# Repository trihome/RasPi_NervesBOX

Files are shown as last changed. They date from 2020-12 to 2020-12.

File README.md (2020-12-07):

# Nerves BOX for Raspberry Pi

## はじめに

このボードは、産業用に使用される機器（例：24V駆動のスイッチ、センサー、リレーなど）をRaspberry Piへ接続できるようにします。

詳しくは、Qiitaの記事「[Elixir/NervesでPLC(多機能リレー)を作ってみた](https://qiita.com/myasu/private/a6664d3a3c76503affc7)」をご覧ください。

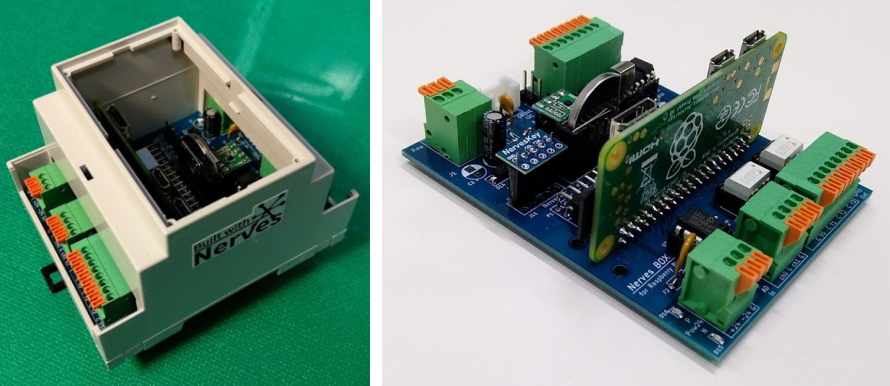
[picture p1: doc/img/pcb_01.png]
pcb01 外観

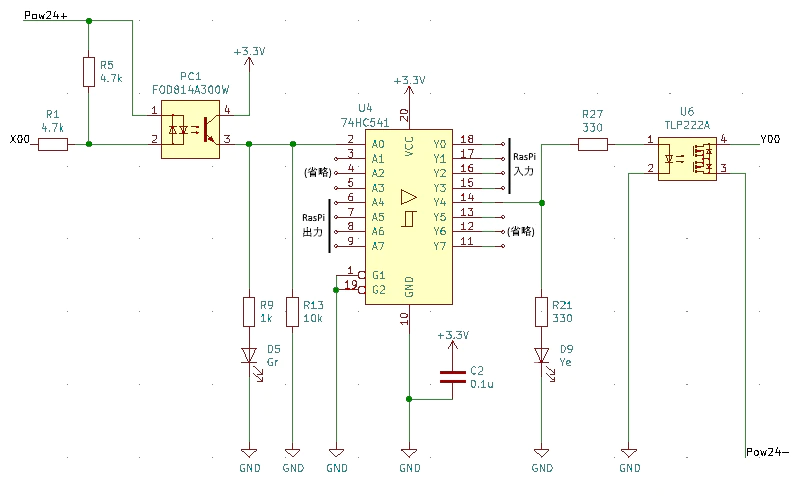
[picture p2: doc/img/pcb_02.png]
pcb02 基板


## 仕様

|機能|仕様|補足|
|:--|:--|:--|
|出力|4ch（フォトリレー絶縁）|シンク（NPN）・ソース（PNP）駆動切り替え可能。各chの動作確認LEDあり。|
|入力|4ch（フォトカプラ絶縁）|〃|
|AD変換|10bit 2ch|非絶縁・入力保護のダイオード付き|
|時刻保持|リアルタイムクロックDS1307|ボタン電池でバックアップ|
|GROVEコネクタ|あり、I2C x 1|5V電源タイプ|
|外部UART端子|あり x 1|RaspberryPiのUARTに直結|
|電源|5V系/24V系は個別に供給|それぞれポリスイッチ（過電流防止）あり|

**J5, J7の接続**

|対応表|GPIO（BCM表記）|本機の端子|
|:--|:--|:--|
|入力|12|X0|
|〃|16|X1|
|〃|20|X2|
|〃|21|X3|
|出力|6|Y0|
|〃|13|Y1|
|〃|19|Y2|
|〃|26|Y3|

**J2の接続**

|駆動したい方法|Pow24+In|Pow24-In||D16|D13||X側COM端子|Y側COM端子|
|:--|:--|:--|:--|:--|:--|:--|:--|:--|
|シンク|+24V|GND|→|点灯|消灯||GND|+24V|
|ソース|GND|+24V|→|消灯|点灯||+24V|GND|

## 作り方

[Manual](doc/README_pcb.jp.md)をご覧ください。

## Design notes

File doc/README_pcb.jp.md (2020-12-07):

# Nerves BOX for Raspberry Pi

## 1.作り方

### (1)PCB

`gerber`ディレクトリの中のファイル一式を、PCB業者に制作依頼します。

（一例）

- [Fusion PCB](https://www.fusionpcb.jp/)
- [P板.com](https://www.p-ban.com/)

#### Fusion PCBでの注文手順

[手順参考](https://github.com/trihome/RasPi_PiFA/blob/master/doc/README_pcb.jp.md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)

※2020年3月時点の手順です。
※費用はPayPalアカウントかクレジットカードで支払います。

### (2)部品表

大半の部品は、秋月電子通商さんで購入できます。
一部、取り扱いのない部品については、マルツオンラインさん、共立電子産業さん、千石電商さんなどから購入可能です。

[部品表](../NBoxRpi.csv)

#### 補足

NPN（シンク）駆動だけで使用する場合は、より入手性の良い（かつ安価な）下記の部品でも対応可能です。
（J2の接続は必ず”シンク”の繋ぎ方にしてください）

|部品番号|変更前|変更後|入手先|
|:--|:--|:--|:--|
|PC1 PC2 PC3 PC4 |FOD814A300W|TLP627|https://akizukidenshi.com/catalog/g/gI-07691/|
|U6 U7 U8 U9 |TLP222A|〃|〃|

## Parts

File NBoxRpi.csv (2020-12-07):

Reference | Quantity | Value | URL
BT1 | 1 | CH243-2032LF | https://akizukidenshi.com/catalog/g/gP-02019/
C3 | 1 | 100uF | https://akizukidenshi.com/catalog/g/gP-03122/
C1 C2 C4 | 3 | 0.1uF | https://akizukidenshi.com/catalog/g/gP-10147/
C5 | 1 | 470uF | https://akizukidenshi.com/catalog/g/gP-10272/
D1 D2 D3 D4 | 4 | 1N4148W | https://akizukidenshi.com/catalog/g/gI-07084/
D10 D16 D13 | 2 | LED Red | https://akizukidenshi.com/catalog/g/gI-03978/
D15 | 1 | SBR1A40SA | https://akizukidenshi.com/catalog/g/gI-07418/
D5 D6 D7 D8 | 4 | LED Greeen | https://akizukidenshi.com/catalog/g/gI-03980/
D9 D11 D12 D14 | 4 | LED Yellow | https://akizukidenshi.com/catalog/g/gI-03984/
F1 | 1 | 0.17A(MAX0.34) | https://akizukidenshi.com/catalog/g/gP-12627/
F2 | 1 | 0.5A(MAX1A) | https://akizukidenshi.com/catalog/g/gP-12628/
J1 | 1 | GROVE CONN | https://www.marutsu.co.jp/pc/i/829425/
J3 J9 | 1 | Pin Header 3 | https://akizukidenshi.com/catalog/g/gC-00167/
J8 | 1 | Pin Header 4 | https://akizukidenshi.com/catalog/g/gC-00167/
J4 | 1 | TB401-1-3-E | https://akizukidenshi.com/catalog/g/gP-01405/
J5 J7 | 1 | TB401-1-8-E | https://akizukidenshi.com/catalog/g/gP-07757/
J6 J2 | 1 | TB401-1-4-E | https://akizukidenshi.com/catalog/g/gP-07756/
P1 | 1 | RasPi CONN | https://www.marutsu.co.jp/pc/i/59246/
R1 R2 R3 R4 R5 R6 R7 R8 R26 R31 | 10 | 4.7k | https://eleshop.jp/shop/g/gABO36V/
R13 R14 R15 R16 R17 R18 R19 R20 R32 R33 R34 R35 R40 R41 | 14 | 10k | https://eleshop.jp/shop/g/gABQ364/
R21 R23 R24 R25 R27 R28 R29 R30 | 8 | 330 | https://eleshop.jp/shop/g/gABO363/
R22 | 1 | 470 | https://eleshop.jp/shop/g/gABO367/
R9 R10 R11 R12 R36 R37 R38 R39 | 8 | 1k | https://eleshop.jp/shop/g/gABO36F/
(ICソケット8Pin) | 4 |  | https://akizukidenshi.com/catalog/g/gP-00017/
U1 | 1 | AE-PCA9306 | https://akizukidenshi.com/catalog/g/gM-05452/
U2 | 1 | MCP3002 | https://akizukidenshi.com/catalog/g/gI-02584/
PC1 PC2 PC3 PC4 | 4 | FOD814A300W | https://akizukidenshi.com/catalog/g/gI-06483/
U6 U7 U8 U9 | 4 | TLP222A | https://akizukidenshi.com/catalog/g/gI-07672/
U3 | 1 | DS1307+ | https://akizukidenshi.com/catalog/g/gI-06950/
U4 | 1 | 74HC541 | https://eleshop.jp/shop/g/gT11631/
U5 | 1 | MCP1703AT-3302E/CB | https://akizukidenshi.com/catalog/g/gI-13612/
Y1 | 1 | 32.768kHz | https://akizukidenshi.com/catalog/g/gP-04005/
ケース(DINモジュールボックス) | 1 | H53-4MG-G | https://www.marutsu.co.jp/pc/i/23031/
ボタン電池 | 1 | CR2032 | (none)

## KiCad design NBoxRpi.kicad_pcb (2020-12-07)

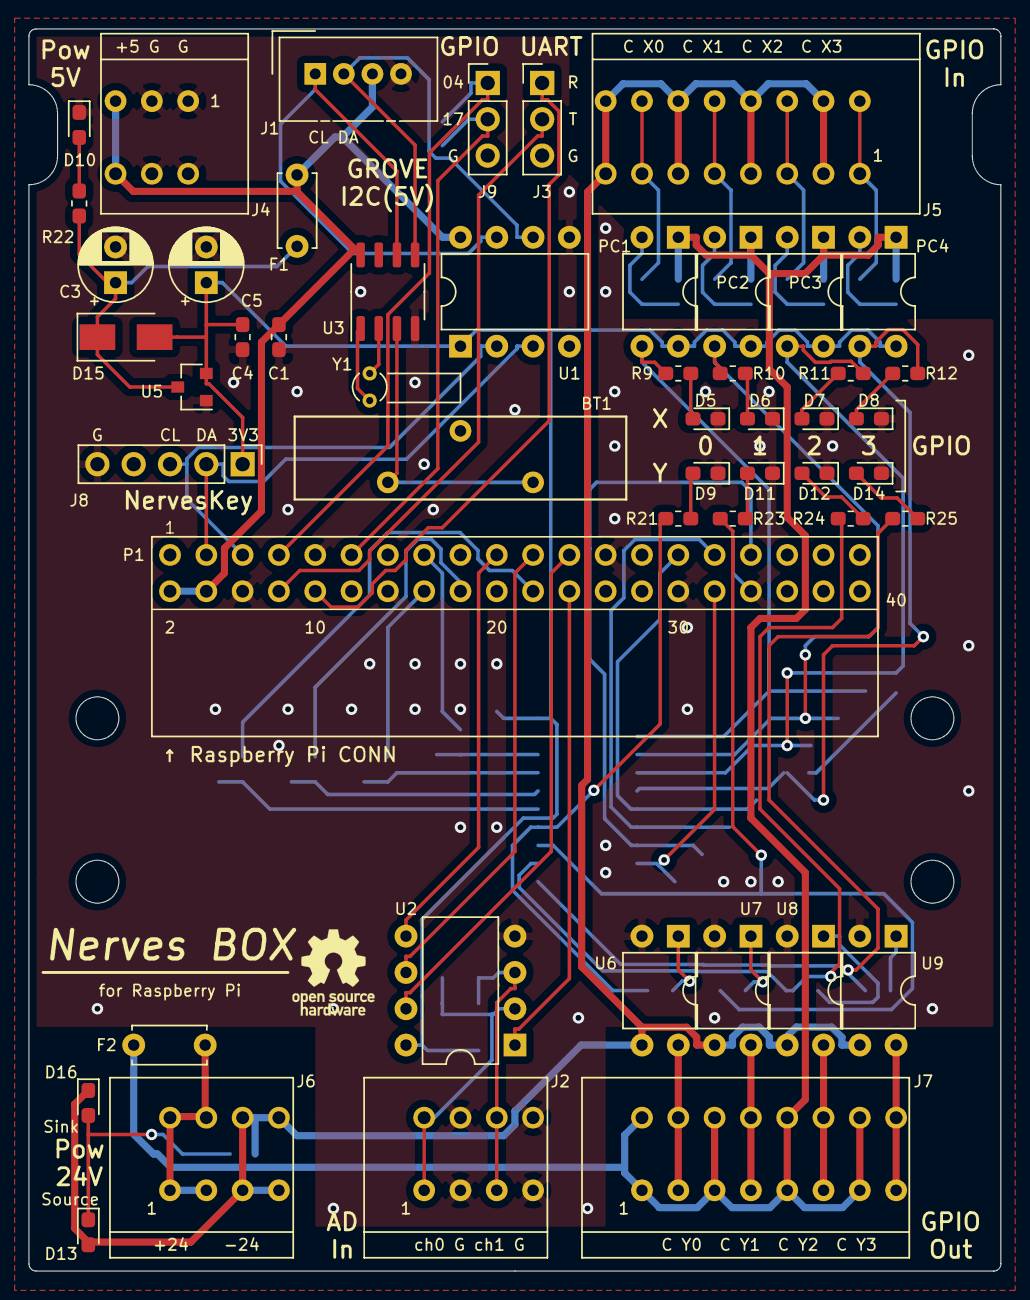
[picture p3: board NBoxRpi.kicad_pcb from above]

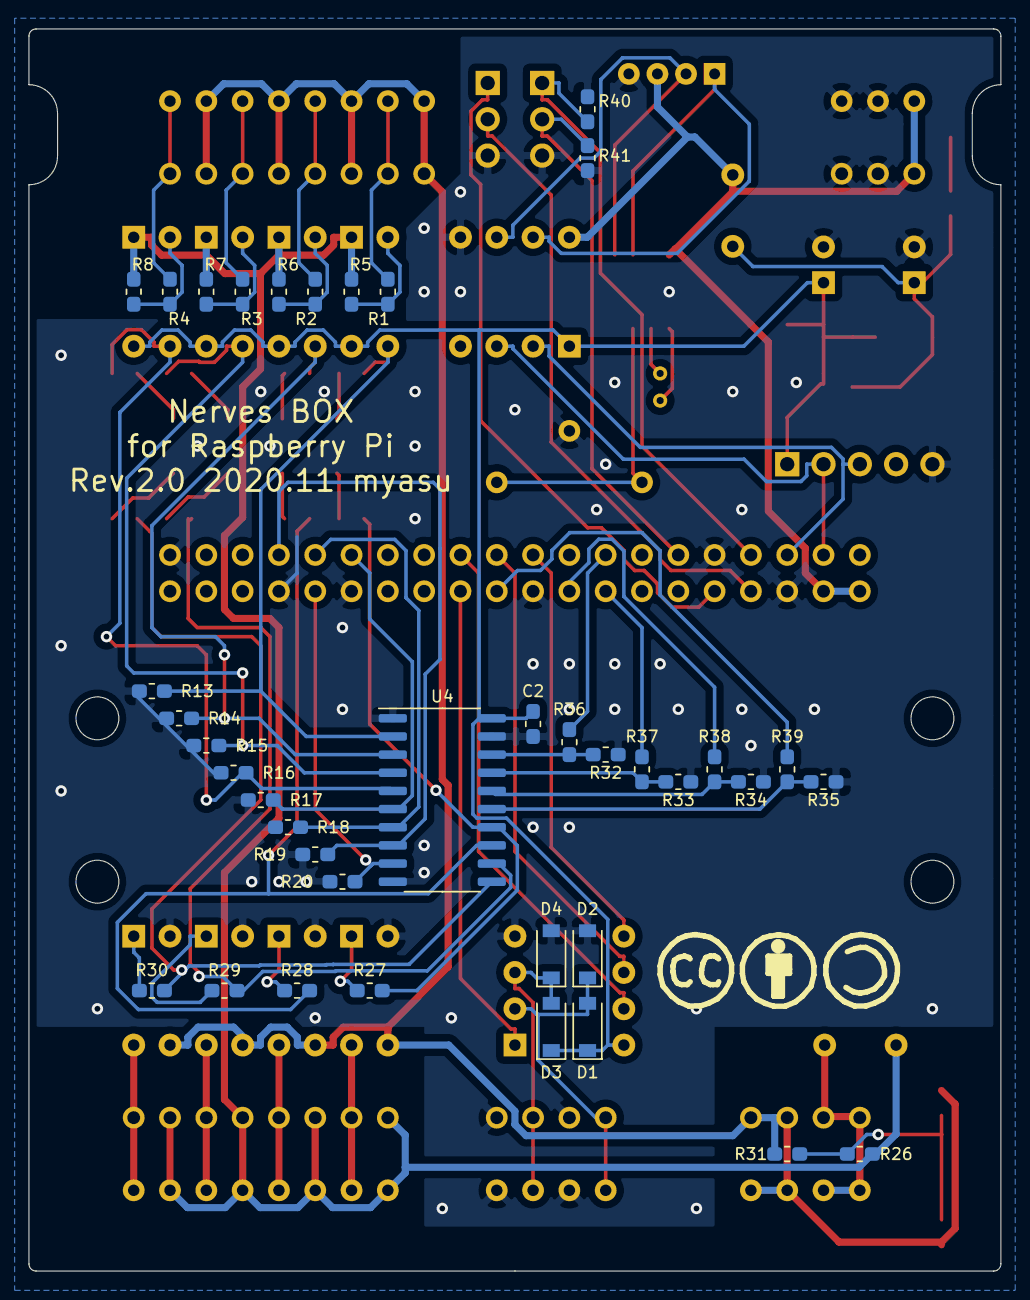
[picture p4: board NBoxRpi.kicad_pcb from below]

Board: 2 copper layers, 68.0 x 86.9 mm, 95 parts (38 on the bottom side), 70 nets.

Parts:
BT1: CH243-2032LF; BatteryHolder_Keystone_CH74-2032LF
C1, C2, C4: 0.1uF; C_0603_1608Metric_Pad1.05x0.95mm_HandSolder
C3: 100uF; CP_Radial_D5.0mm_P2.50mm
C5: 220uF; CP_Radial_D5.0mm_P2.50mm
D1, D2, D3, D4: 1N4148W; D_SOD-123
D5, D6, D7, D8: Gr; LED_0603_1608Metric_Pad1.05x0.95mm_HandSolder
D9, D11, D12, D14: Ye; LED_0603_1608Metric_Pad1.05x0.95mm_HandSolder
D10, D13, D16: Red; LED_0603_1608Metric_Pad1.05x0.95mm_HandSolder
D15: SBR1A40SA; D_SMA
F1: 0.17A(MAX0.34); C_Disc_D5.0mm_W2.5mm_P5.00mm
F2: 0.5A(MAX1A); C_Disc_D5.0mm_W2.5mm_P5.00mm
H1: MountingHole; OSHW-Logo_5.7x6mm_SilkScreen
H2: MountingHole; CC-BY-SA
J1: GROVE CONN; NS-Tech_Grove_1x04_P2mm_Vertical
J2, J6: TB401-1-4-E; Terminal_TB401-1-4-E
J3, J9: Pin Header 3; PinHeader_1x03_P2.54mm_Vertical
J4: TB401-1-3-E; Terminal_TB401-1-3-E
J5: TB401-1-8-E; Terminal_TB401-1-8-E
J7: TB401-1-3-E; Terminal_TB401-1-8-E
J8: Pin Header 4; PinHeader_1x05_P2.54mm_Vertical
MH1, MH2, MH3, MH4: MountingHole; MountingHole_3mm
P1: RasPi CONN; Connector_21602X20GRE
PC1, PC2, PC3, PC4: FOD814A300W; DIP-4_W7.62mm
R1, R2, R3, R4, R5, R6, R7, R8, R26, R31: 4.7k; R_0603_1608Metric_Pad1.05x0.95mm_HandSolder
R9, R10, R11, R12, R36, R37, R38, R39: 1k; R_0603_1608Metric_Pad1.05x0.95mm_HandSolder
R13, R14, R15, R16, R17, R18, R19, R20, R32, R33, R34, R35, R40, R41: 10k; R_0603_1608Metric_Pad1.05x0.95mm_HandSolder
R21, R23, R24, R25, R27, R28, R29, R30: 330; R_0603_1608Metric_Pad1.05x0.95mm_HandSolder
R22: 470; R_0603_1608Metric_Pad1.05x0.95mm_HandSolder
U1: AE-PCA9306; DIP-8_W7.62mm
U2: MCP3002; DIP-8_W7.62mm
U3: DS1307+; SO-8_3.9x4.9mm_P1.27mm
U4: 74HC541; SO-20_5.3x12.6mm_P1.27mm
U5: MCP1703AT-3302E; SOT-23
U6, U7, U8, U9: TLP222A; DIP-4_W7.62mm
Y1: 32.768kHz; Crystal_Round_D2.0mm_Vertical

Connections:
+3V3: C2.1, C4.1, C5.1, D1.1, D3.1, D15.2, J8.1, PC1.4, PC2.4, PC3.4, PC4.4, U1.1, U2.8, U4.20, U5.2
+5V: C1.1, F1.2, J1.3, J4.5, J4.6, P1.2, P1.4, U1.8, U3.8
/AD0: D1.2, D2.1, J2.1, J2.2, U2.2
/AD1: D3.2, D4.1, J2.5, J2.6, U2.3
/GPIO2(SDA1): J8.2, P1.3, U1.3
/GPIO3(SCL1): J8.3, P1.5, U1.2
/GPIO4(GCLK): J9.1, P1.7, R40.1
/GPIO5: P1.29, R17.1, U4.6
/GPIO6: P1.31, R18.1, U4.7
/GPIO8(SPI0_CE_N): P1.24, U2.1
/GPIO9(SPI0_MISO): P1.21, U2.6
/GPIO10(SPI0_MOSI): P1.19, U2.5
/GPIO11(SPI0_SCK): P1.23, U2.7
/GPIO12(PWM0): P1.32, R20.1, U4.9
/GPIO13(PWM1): P1.33, R19.1, U4.8
/GPIO14(TXD0): J3.2, P1.8
/GPIO15(RXD0): J3.1, P1.10
/GPIO17(GEN0): J9.2, P1.11, R41.1
/GPIO22(GEN3): P1.15, R36.1
/GPIO23(GEN4): P1.16, R37.1
/GPIO24(GEN5): P1.18, R38.1
/GPIO25(GEN6): P1.22, R39.1
/Pow24+: F2.1, J7.1, J7.2, J7.5, J7.6, J7.9, J7.10, J7.13, J7.14, PC1.1, PC2.1, PC3.1, PC4.1, R5.1, R6.1, R7.1, R8.1, R26.1
/Pow24+In: F2.2, J6.1, J6.2, J6.3, J6.4
/Pow24-: D13.2, D16.1, J5.3, J5.4, J5.7, J5.8, J5.11, J5.12, J5.15, J5.16, J6.5, J6.6, J6.7, J6.8, R31.2, U6.3, U7.3, U8.3, U9.3
/SCL: J1.1, U1.7, U3.6
/SDA: J1.2, U1.6, U3.5
/X00: J5.13, J5.14, R1.2
/X01: J5.9, J5.10, R2.2
/X02: J5.5, J5.6, R3.2
/X03: J5.1, J5.2, R4.2
/Y00: J7.3, J7.4, U6.4
/Y01: J7.7, J7.8, U7.4
/Y02: J7.11, J7.12, U8.4
/Y03: J7.15, J7.16, U9.4
GND: BT1.2, C1.2, C2.2, C3.2, C4.2, C5.2, D2.2, D4.2, D5.1, D6.1, D7.1, D8.1, D9.1, D10.1, D11.1, D12.1, D14.1, J1.4, J2.3, J2.4, J2.7, J2.8, J3.3, J4.1, J4.2, J4.3, J4.4, J8.5, J9.3, P1.6, P1.9, P1.14, P1.20, P1.25, P1.30, P1.34, P1.39, R13.2, R14.2, R15.2, R16.2, R17.2, R18.2, R19.2, R20.2, R32.2, R33.2, R34.2, R35.2, R40.2, R41.2, U1.5, U2.4, U3.4, U4.1, U4.10, U4.19, U5.1, U6.2, U7.2, U8.2, U9.2
unnamed: BT1.1, U3.3
unnamed: C3.1, D15.1, F1.1, R22.1, U5.3
unnamed: D5.2, R9.2
unnamed: D6.2, R10.2
unnamed: D7.2, R11.2
unnamed: D8.2, R12.2
unnamed: D9.2, R21.2
unnamed: D10.2, R22.2
unnamed: D11.2, R23.2
unnamed: D12.2, R24.2
unnamed: D13.1, D16.2, R26.2, R31.1
unnamed: D14.2, R25.2
unnamed: PC1.2, R1.1, R5.2
unnamed: PC1.3, R9.1, R13.1, U4.2
unnamed: PC2.2, R2.1, R6.2
unnamed: PC2.3, R10.1, R14.1, U4.3
unnamed: PC3.2, R3.1, R7.2
unnamed: PC3.3, R11.1, R15.1, U4.4
unnamed: PC4.2, R4.1, R8.2
unnamed: PC4.3, R12.1, R16.1, U4.5
unnamed: R21.1, R27.2, U4.14
unnamed: R23.1, R28.2, U4.13
unnamed: R24.1, R29.2, U4.12
unnamed: R25.1, R30.2, U4.11
unnamed: R27.1, U6.1
unnamed: R28.1, U7.1
unnamed: R29.1, U8.1
unnamed: R30.1, U9.1
unnamed: R32.1, R36.2, U4.18
unnamed: R33.1, R37.2, U4.17
unnamed: R34.1, R38.2, U4.16
unnamed: R35.1, R39.2, U4.15
unnamed: U3.1, Y1.1
unnamed: U3.2, Y1.2

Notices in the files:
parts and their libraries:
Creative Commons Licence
